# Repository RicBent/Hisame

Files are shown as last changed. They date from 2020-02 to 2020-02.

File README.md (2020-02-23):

# Hisame  
氷雨 - IceStorm

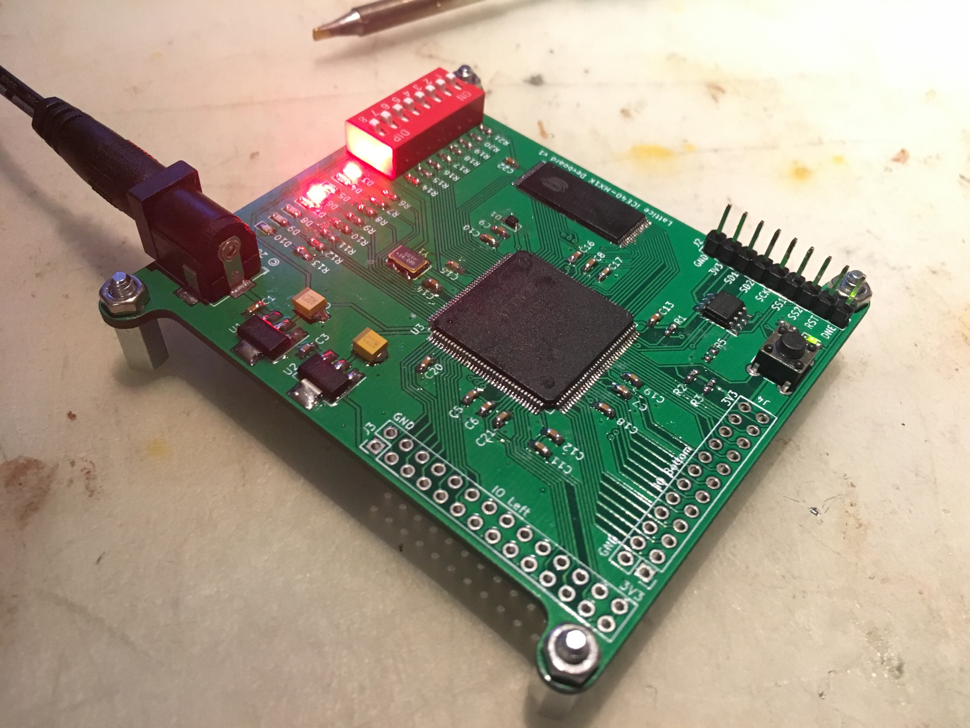
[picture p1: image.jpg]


### Development board for the Lattice iCE40 HX1K FPGA

Features:

* 8 LEDs
* 8 Switches
* On board Oscillator
* 128K SRAM
* 44 available IO on header pins

It allows 3 modes of operation:

1. Configuring from SPI flash memory
2. Configuring from an external SPI master device such as a Raspberry Pi (3.3V!)
3. Programming the SPI flash memory from an external SPI master device

Binaries can be built with the IceStorm toolchain or the official Lattice tools.

Bugs:

* GNDPLL is connected to Ground. Using the PLLs might cause issues.
* For FPGA configuration from SPI flash SS and CS_FLASH must be connected.  
  Fix: Don't place R5 and put a jumper between SS1 and SS2 when FPGA should configure from SPI flash.

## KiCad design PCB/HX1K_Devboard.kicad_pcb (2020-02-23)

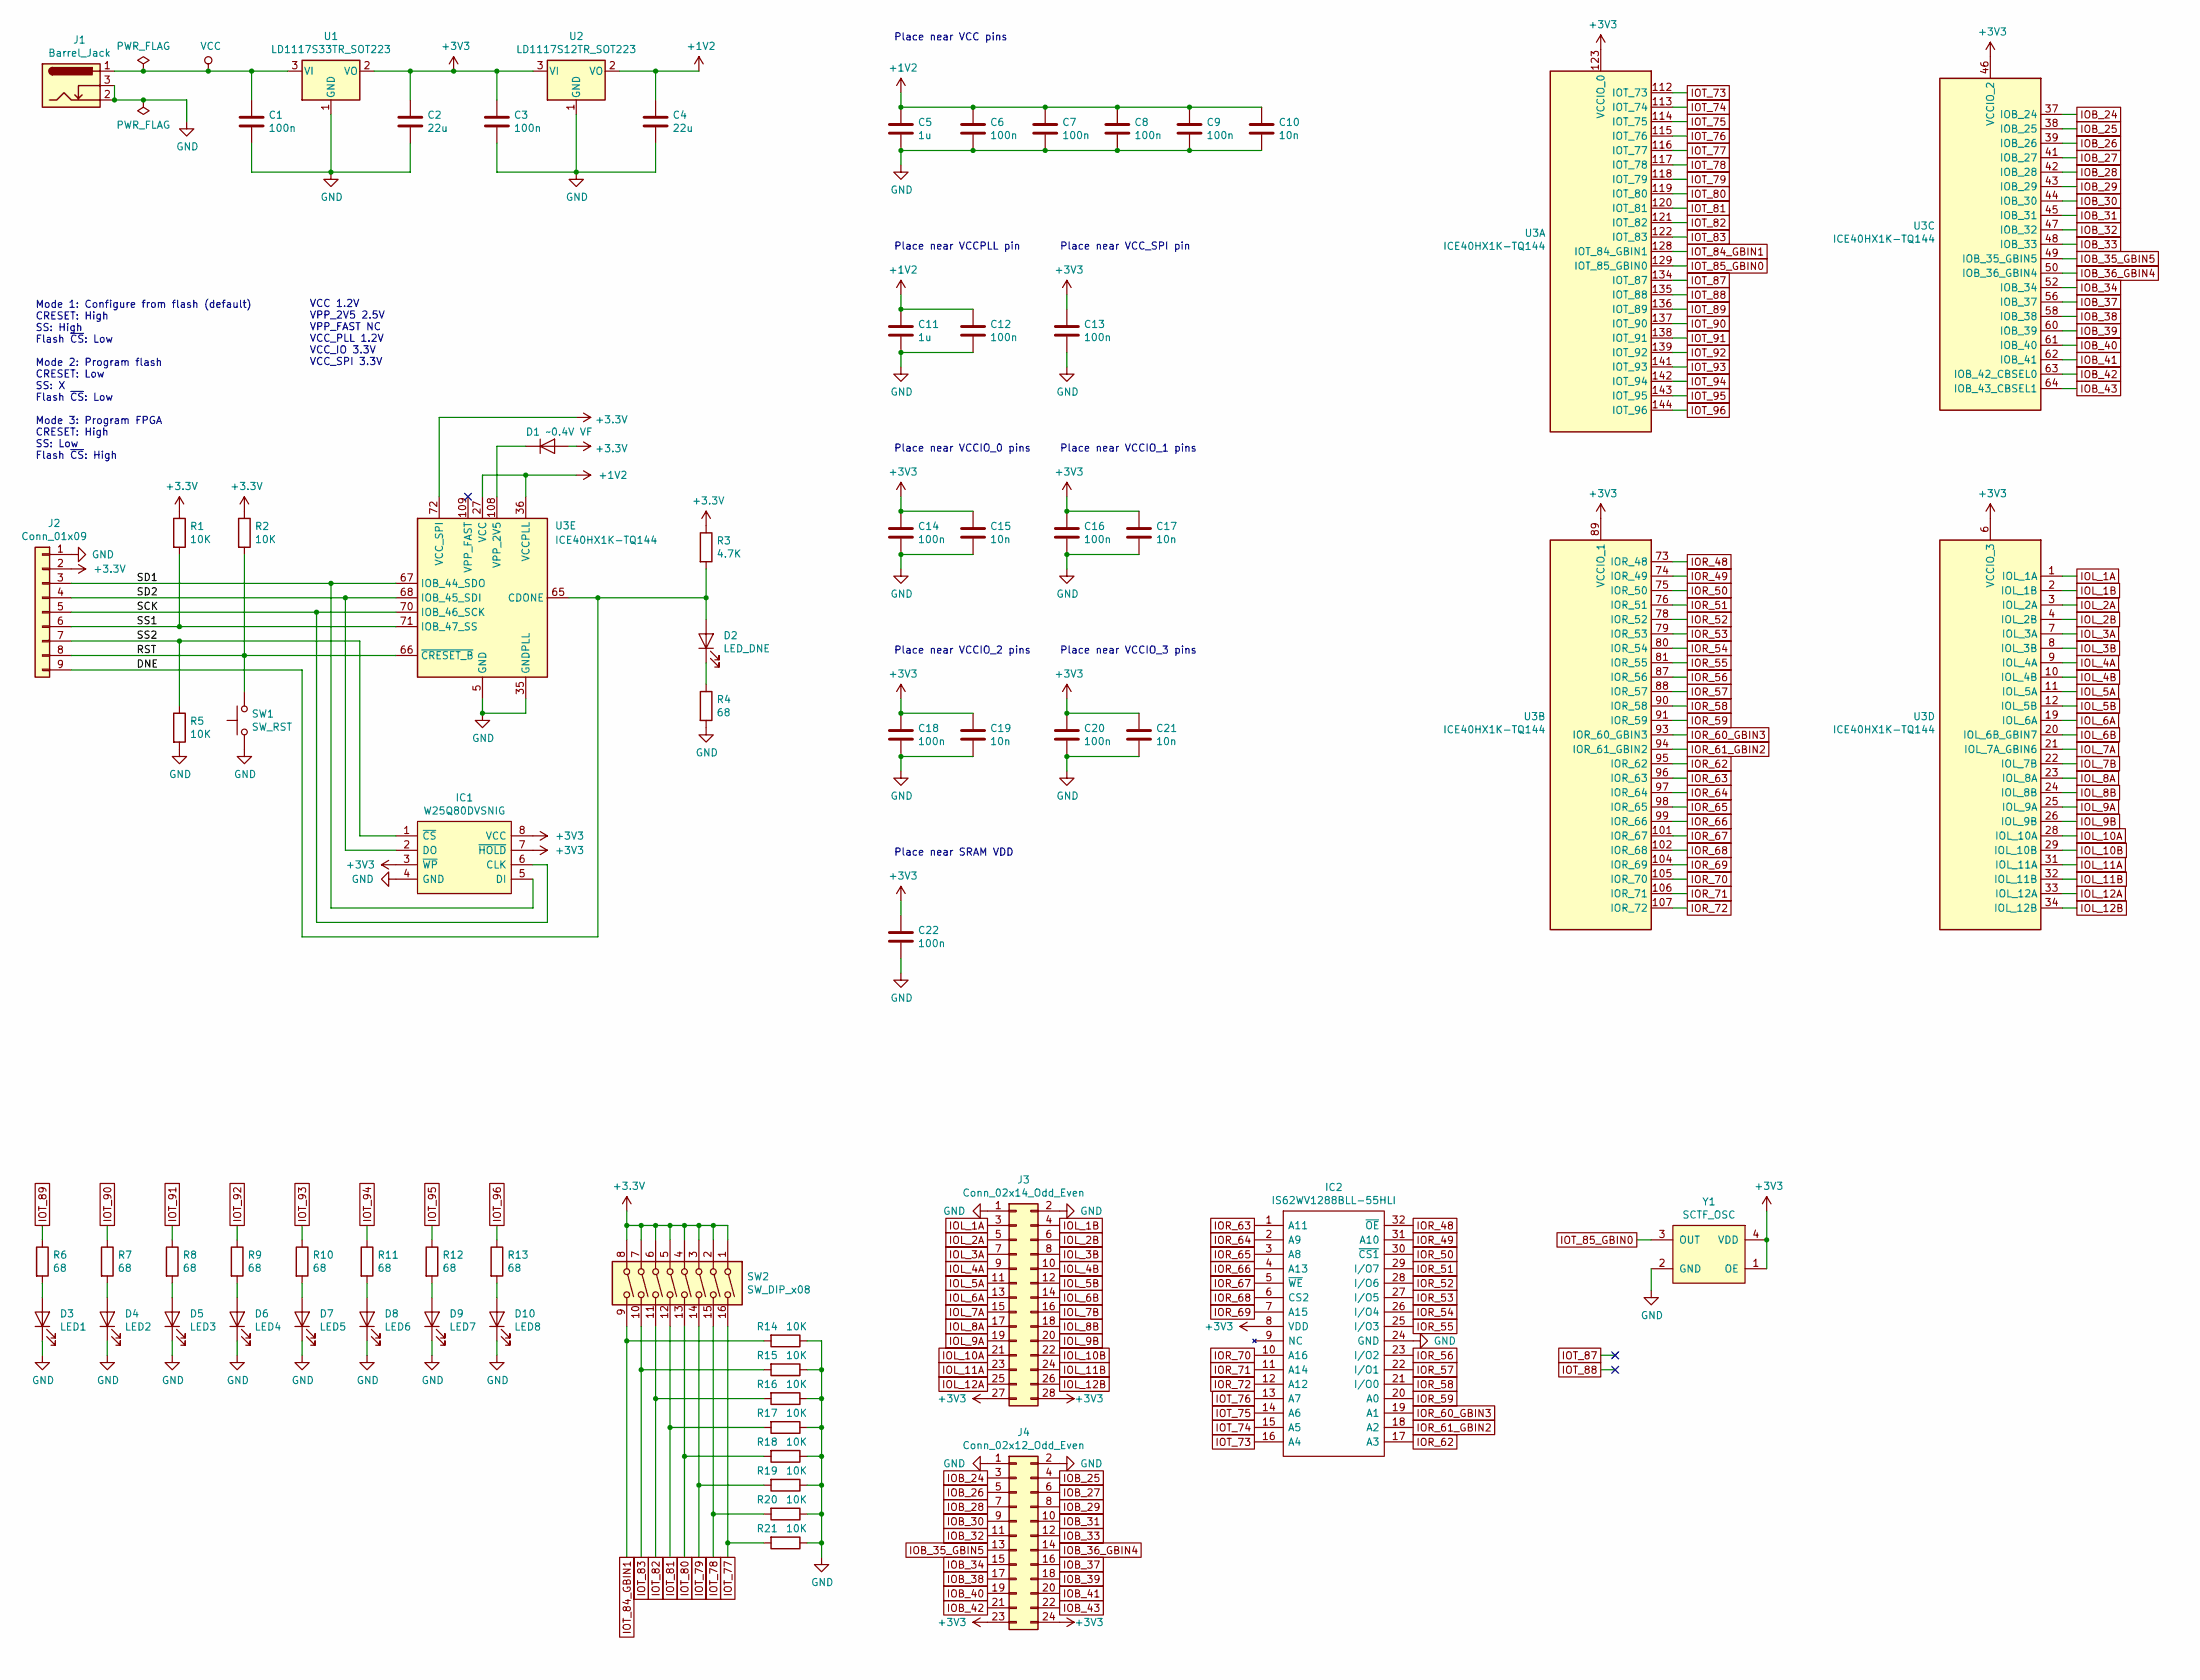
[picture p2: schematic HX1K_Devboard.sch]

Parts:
C1, C3, C6, C7, C8, C9, C12, C13, C14, C16, C18, C20, C22: 100n; C_0603_1608Metric_Pad1.05x0.95mm_HandSolder
C2, C4: 22u; CP_EIA-3216-18_Kemet-A_Pad1.58x1.35mm_HandSolder
C5, C11: 1u; C_0603_1608Metric_Pad1.05x0.95mm_HandSolder
C10, C15, C17, C19, C21: 10n; C_0603_1608Metric_Pad1.05x0.95mm_HandSolder
D1: ~~0.4V VF; D_SOD-323
D2: LED_DNE; LED_0603_1608Metric_Pad1.05x0.95mm_HandSolder
D3: LED1; LED_0603_1608Metric_Pad1.05x0.95mm_HandSolder
D4: LED2; LED_0603_1608Metric_Pad1.05x0.95mm_HandSolder
D5: LED3; LED_0603_1608Metric_Pad1.05x0.95mm_HandSolder
D6: LED4; LED_0603_1608Metric_Pad1.05x0.95mm_HandSolder
D7: LED5; LED_0603_1608Metric_Pad1.05x0.95mm_HandSolder
D8: LED6; LED_0603_1608Metric_Pad1.05x0.95mm_HandSolder
D9: LED7; LED_0603_1608Metric_Pad1.05x0.95mm_HandSolder
D10: LED8; LED_0603_1608Metric_Pad1.05x0.95mm_HandSolder
IC1: W25Q80DVSNIG; SOIC127P600X175-8N; Manufacturer_Part_Number W25Q80DVSNIG
IC2: IS62WV1288BLL-55HLI; SOP50P2000X120-32N; Manufacturer_Part_Number IS62WV1288BLL-55HLI; Mouser Part Number 87062WV1288BLL55HLI
J1: Barrel_Jack; BarrelJack_Horizontal
J2: Conn_01x09; PinHeader_1x09_P2.54mm_Vertical
J3: Conn_02x14_Odd_Even; PinHeader_2x14_P2.54mm_Vertical
J4: Conn_02x12_Odd_Even; PinHeader_2x12_P2.54mm_Vertical
R1, R2, R5, R14, R15, R16, R17, R18, R19, R20, R21: 10K; R_0603_1608Metric_Pad1.05x0.95mm_HandSolder
R3: 4.7K; R_0603_1608Metric_Pad1.05x0.95mm_HandSolder
R4, R6, R7, R8, R9, R10, R11, R12, R13: 68; R_0603_1608Metric_Pad1.05x0.95mm_HandSolder
SW1: SW_RST; SW_PUSH_6mm
SW2: SW_DIP_x08; SW_DIP_SPSTx08_Slide_9.78x22.5mm_W7.62mm_P2.54mm
U1: LD1117S33TR_SOT223; SOT-223
U2: LD1117S12TR_SOT223; SOT-223
U3: ICE40HX1K-TQ144; TQFP-144_20x20mm_P0.5mm
Y1: SCTF_OSC; Oscillator_SCTF_5032

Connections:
+1V2: C4.1, C5.1, C6.1, C7.1, C8.1, C9.1, C10.1, C11.1, C12.1, U2.2 (VO), U3.27 (VCC), U3.36 (VCCPLL), U3.51 (VCC), U3.92 (VCC), U3.111 (VCC)
/DNE: D2.2 (A), J2.9, R3.2, U3.65 (CDONE)
/RST: J2.8, R2.2, SW1.2, U3.66 (~CRESET_B)
/SCK: IC1.6 (CLK), J2.5, U3.70 (IOB_46_SCK)
/SD1: IC1.5 (DI), J2.3, U3.67 (IOB_44_SDO)
/SD2: IC1.2 (DO), J2.4, U3.68 (IOB_45_SDI)
/SS1: J2.6, R1.2, U3.71 (IOB_47_SS)
/SS2: IC1.1 (~CS), J2.7, R5.1
GND: C1.2, C2.2, C3.2, C4.2, C5.2, C6.2, C7.2, C8.2, C9.2, C10.2, C11.2, C12.2, C13.2, C14.2, C15.2, C16.2, C17.2, C18.2, C19.2, C20.2, C21.2, C22.2, D3.1 (K), D4.1 (K), D5.1 (K), D6.1 (K), D7.1 (K), D8.1 (K), D9.1 (K), D10.1 (K), IC1.4 (GND), IC2.24 (GND), J1.2, J1.3, J2.1, J3.1, J3.2, J4.1, J4.2, R4.2, R5.2, R14.1, R15.1, R16.1, R17.1, R18.1, R19.1, R20.1, R21.1, SW1.1, U1.1 (GND), U2.1 (GND), U3.5 (GND), U3.13 (GND), U3.14 (GND), U3.35 (GNDPLL), U3.59 (GND), U3.69 (GND), U3.86 (GND), U3.103 (GND), U3.132 (GND), U3.140 (GND), Y1.2 (GND)
IOB_24: J4.3, U3.37 (IOB_24)
IOB_25: J4.4, U3.38 (IOB_25)
IOB_26: J4.5, U3.39 (IOB_26)
IOB_27: J4.6, U3.41 (IOB_27)
IOB_28: J4.7, U3.42 (IOB_28)
IOB_29: J4.8, U3.43 (IOB_29)
IOB_30: J4.9, U3.44 (IOB_30)
IOB_31: J4.10, U3.45 (IOB_31)
IOB_32: J4.11, U3.47 (IOB_32)
IOB_33: J4.12, U3.48 (IOB_33)
IOB_34: J4.15, U3.52 (IOB_34)
IOB_35_GBIN5: J4.13, U3.49 (IOB_35_GBIN5)
IOB_36_GBIN4: J4.14, U3.50 (IOB_36_GBIN4)
IOB_37: J4.16, U3.56 (IOB_37)
IOB_38: J4.17, U3.58 (IOB_38)
IOB_39: J4.18, U3.60 (IOB_39)
IOB_40: J4.19, U3.61 (IOB_40)
IOB_41: J4.20, U3.62 (IOB_41)
IOB_42: J4.21, U3.63 (IOB_42_CBSEL0)
IOB_43: J4.22, U3.64 (IOB_43_CBSEL1)
IOL_1A: J3.3, U3.1 (IOL_1A)
IOL_1B: J3.4, U3.2 (IOL_1B)
IOL_2A: J3.5, U3.3 (IOL_2A)
IOL_2B: J3.6, U3.4 (IOL_2B)
IOL_3A: J3.7, U3.7 (IOL_3A)
IOL_3B: J3.8, U3.8 (IOL_3B)
IOL_4A: J3.9, U3.9 (IOL_4A)
IOL_4B: J3.10, U3.10 (IOL_4B)
IOL_5A: J3.11, U3.11 (IOL_5A)
IOL_5B: J3.12, U3.12 (IOL_5B)
IOL_6A: J3.13, U3.19 (IOL_6A)
IOL_6B: J3.14, U3.20 (IOL_6B_GBIN7)
IOL_7A: J3.15, U3.21 (IOL_7A_GBIN6)
IOL_7B: J3.16, U3.22 (IOL_7B)
IOL_8A: J3.17, U3.23 (IOL_8A)
IOL_8B: J3.18, U3.24 (IOL_8B)
IOL_9A: J3.19, U3.25 (IOL_9A)
IOL_9B: J3.20, U3.26 (IOL_9B)
IOL_10A: J3.21, U3.28 (IOL_10A)
IOL_10B: J3.22, U3.29 (IOL_10B)
IOL_11A: J3.23, U3.31 (IOL_11A)
IOL_11B: J3.24, U3.32 (IOL_11B)
IOL_12A: J3.25, U3.33 (IOL_12A)
IOL_12B: J3.26, U3.34 (IOL_12B)
IOR_48: IC2.32 (~OE), U3.73 (IOR_48)
IOR_49: IC2.31 (A10), U3.74 (IOR_49)
IOR_50: IC2.30 (~CS1), U3.75 (IOR_50)
IOR_51: IC2.29 (I/O7), U3.76 (IOR_51)
IOR_52: IC2.28 (I/O6), U3.78 (IOR_52)
IOR_53: IC2.27 (I/O5), U3.79 (IOR_53)
IOR_54: IC2.26 (I/O4), U3.80 (IOR_54)
IOR_55: IC2.25 (I/O3), U3.81 (IOR_55)
IOR_56: IC2.23 (I/O2), U3.87 (IOR_56)
IOR_57: IC2.22 (I/O1), U3.88 (IOR_57)
IOR_58: IC2.21 (I/O0), U3.90 (IOR_58)
IOR_59: IC2.20 (A0), U3.91 (IOR_59)
IOR_60_GBIN3: IC2.19 (A1), U3.93 (IOR_60_GBIN3)
IOR_61_GBIN2: IC2.18 (A2), U3.94 (IOR_61_GBIN2)
IOR_62: IC2.17 (A3), U3.95 (IOR_62)
IOR_63: IC2.1 (A11), U3.96 (IOR_63)
IOR_64: IC2.2 (A9), U3.97 (IOR_64)
IOR_65: IC2.3 (A8), U3.98 (IOR_65)
IOR_66: IC2.4 (A13), U3.99 (IOR_66)
IOR_67: IC2.5 (~WE), U3.101 (IOR_67)
IOR_68: IC2.6 (CS2), U3.102 (IOR_68)
IOR_69: IC2.7 (A15), U3.104 (IOR_69)
IOR_70: IC2.10 (A16), U3.105 (IOR_70)
IOR_71: IC2.11 (A14), U3.106 (IOR_71)
IOR_72: IC2.12 (A12), U3.107 (IOR_72)
IOT_73: IC2.16 (A4), U3.112 (IOT_73)
IOT_74: IC2.15 (A5), U3.113 (IOT_74)
IOT_75: IC2.14 (A6), U3.114 (IOT_75)
IOT_76: IC2.13 (A7), U3.115 (IOT_76)
IOT_77: R21.2, SW2.16, U3.116 (IOT_77)
IOT_78: R20.2, SW2.15, U3.117 (IOT_78)
IOT_79: R19.2, SW2.14, U3.118 (IOT_79)
IOT_80: R18.2, SW2.13, U3.119 (IOT_80)
IOT_81: R17.2, SW2.12, U3.120 (IOT_81)
IOT_82: R16.2, SW2.11, U3.121 (IOT_82)
IOT_83: R15.2, SW2.10, U3.122 (IOT_83)
IOT_84_GBIN1: R14.2, SW2.9, U3.128 (IOT_84_GBIN1)
IOT_85_GBIN0: U3.129 (IOT_85_GBIN0), Y1.3 (OUT)
IOT_87: U3.134 (IOT_87)
IOT_88: U3.135 (IOT_88)
IOT_89: R6.1, U3.136 (IOT_89)
IOT_90: R7.1, U3.137 (IOT_90)
IOT_91: R8.1, U3.138 (IOT_91)
IOT_92: R9.1, U3.139 (IOT_92)
IOT_93: R10.1, U3.141 (IOT_93)
IOT_94: R11.1, U3.142 (IOT_94)
IOT_95: R12.1, U3.143 (IOT_95)
IOT_96: R13.1, U3.144 (IOT_96)
unnamed: D1.1 (K), U3.108 (VPP_2V5)
unnamed: D2.1 (K), R4.1
unnamed: D3.2 (A), R6.2
unnamed: D4.2 (A), R7.2
unnamed: D5.2 (A), R8.2
unnamed: D6.2 (A), R9.2
unnamed: D7.2 (A), R10.2
unnamed: D8.2 (A), R11.2
unnamed: D9.2 (A), R12.2
unnamed: D10.2 (A), R13.2
VCC: C1.1, J1.1, U1.3 (VI)

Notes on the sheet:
VCC 1.2V VPP_2V5 2.5V VPP_FAST NC VCC_PLL 1.2V VCC_IO 3.3V VCC_SPI 3.3V
Mode 1: Configure from flash (default) CRESET: High SS: High Flash ~CS~: Low Mode 2: Program flash CRESET: Low SS: X Flash ~CS~: Low Mode 3: Program FPGA CRESET: High SS: Low Flash ~CS~: High
Place near VCC pins
Place near VCCPLL pin
Place near VCC_SPI pin
Place near VCCIO_0 pins
Place near VCCIO_1 pins
Place near VCCIO_2 pins
Place near VCCIO_3 pins
Place near SRAM VDD

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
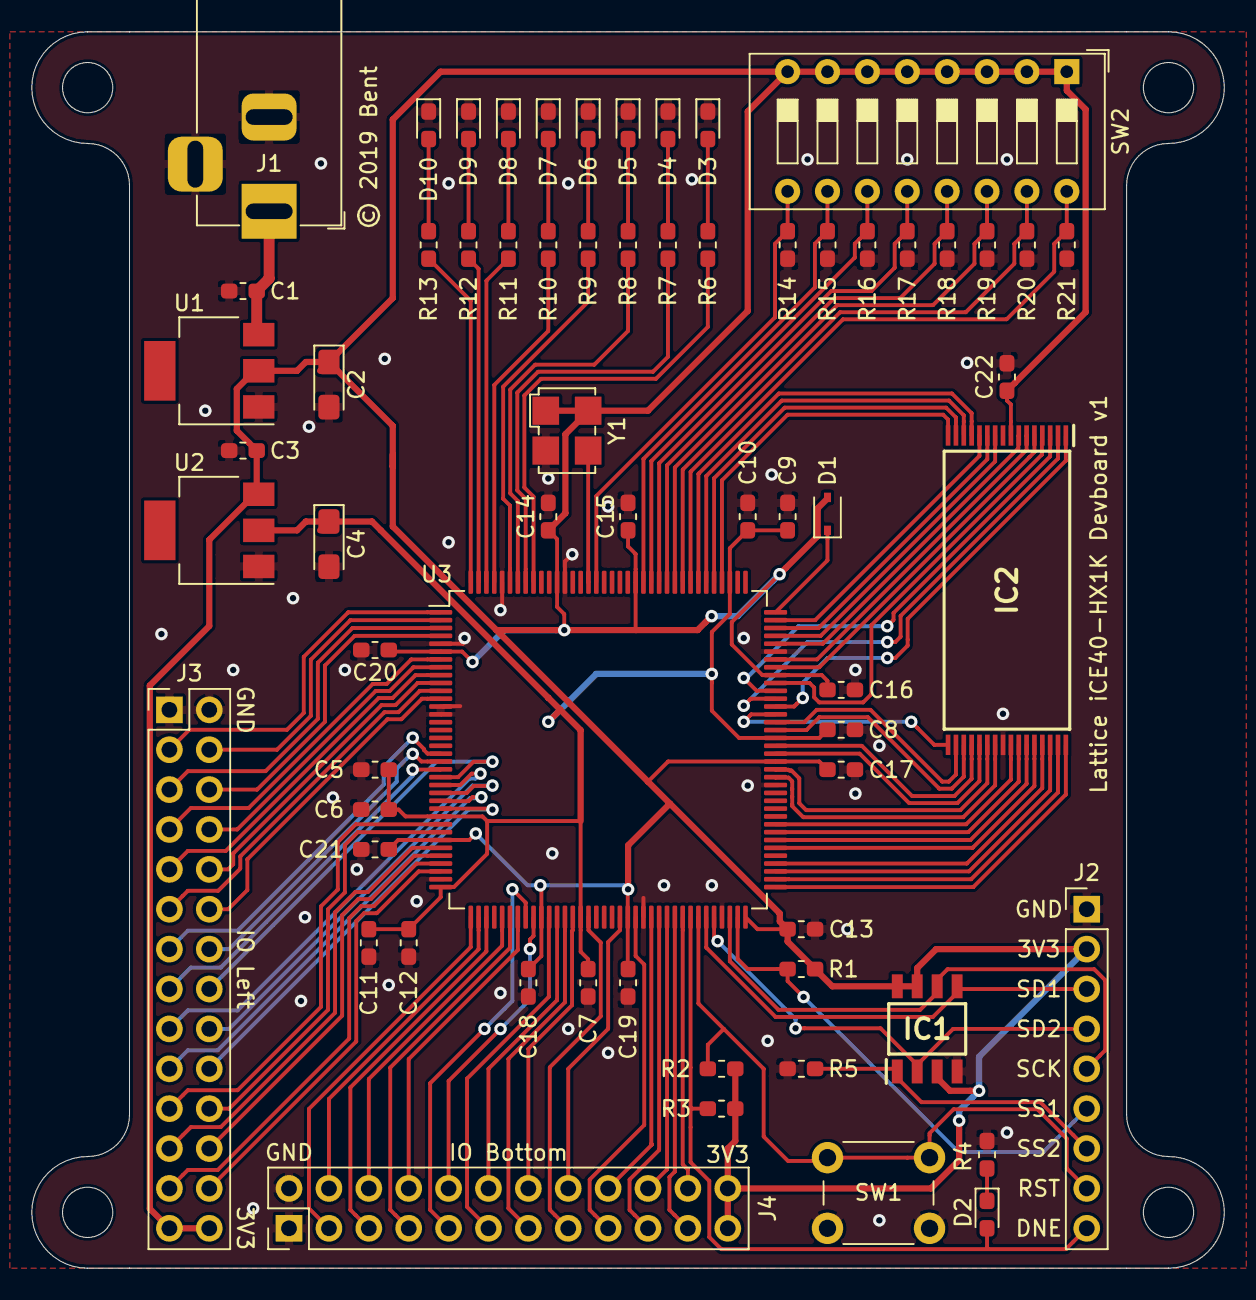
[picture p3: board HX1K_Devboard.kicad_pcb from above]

Board: 2 copper layers, 75.9 x 78.7 mm, 65 parts (0 on the bottom side), 111 nets.

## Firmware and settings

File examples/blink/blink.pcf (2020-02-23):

set_io clk 129

set_io sw1 116
set_io sw2 117
set_io sw3 118
set_io sw4 119
set_io sw5 120
set_io sw6 121
set_io sw7 122
set_io sw8 128

set_io led1 136
set_io led2 137
set_io led3 138
set_io led4 139
set_io led5 141
set_io led6 142
set_io led7 143
set_io led8 144

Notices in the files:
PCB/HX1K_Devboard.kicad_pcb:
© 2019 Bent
